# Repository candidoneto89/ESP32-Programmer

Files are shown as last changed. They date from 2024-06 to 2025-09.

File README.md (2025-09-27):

# ESP32-Programmer

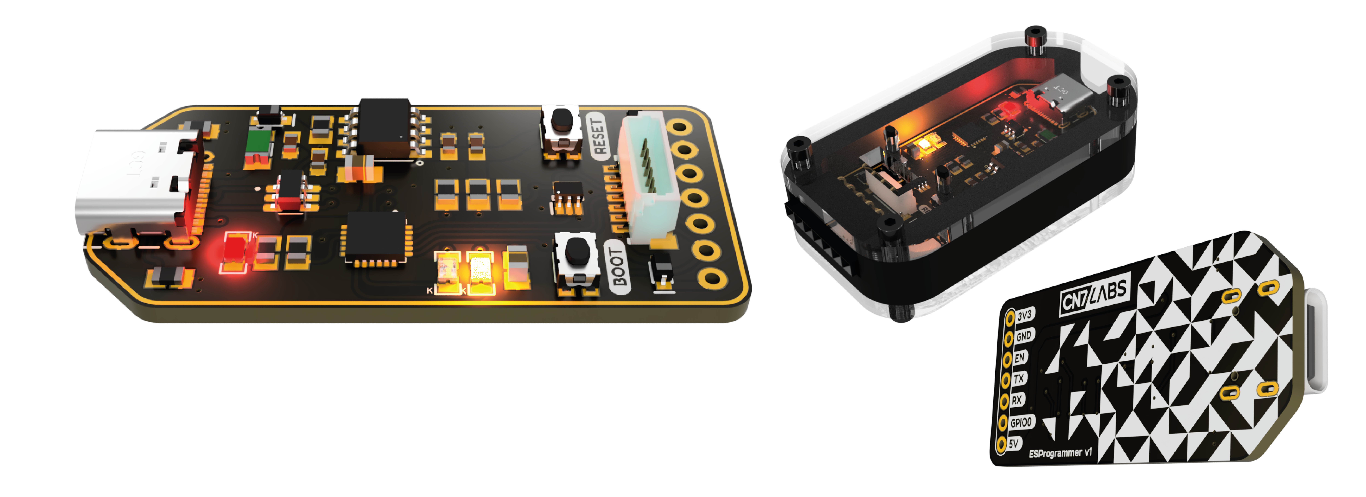
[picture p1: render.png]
ESP32 Programmer


This is a serial bridge for programming custom ESP32 boards, with auto-reset feature, so you shouldn't have to manually push buttons to enter boot mode. The board can also power simple ESP32 boards and has some standard circuit protections. 

**Features:**
- USB-C Connector
- ESD, overcurrent and reverse current protection
- CP2104 enabled USB-to-UART Bridge
- 3.3V ~ 600mA regulator
- Auto-reset circuit
- Boot and Reset buttons.
  
# Building
## PCB BOM

|Parts |Value |Package |Qty|
|---|---|---|---|
|C1, C2, C5 |10uF |0603-CAP |3  |
|C3 |1uF |0603-CAP |1  |
|C4 |10uF |C0805 |1  |
|C6 |1uF |C0805 |1  |
|D1, D2, D3 |BAT60A |SOD-323 |3  |
|F1 |1.5A PTC FUSE |PTC1206 |1  |
|J2 |USB-C-4105_REVA |GCT_USB4105_REVA |1  |
|PWR |RED LED |0805_LED |1  |
|Q1 |UMH3N |SOT65P230X110-6N |1  |
|R3, R4, R10|5.1k |R0805 |3  |
|R5, R8, R9 |10k |R0805 |3  |
|R6 |4.7k |R0805 |1  |
|R7 |100k |R0805 |1  |
|RX |YELLOW LED |0805_LED |1  |
|S1, S2 |KMR621NG SWITCH |KMR621NG_LFS |2  |
|TX |ORANGE LED |0805_LED |1  |
|U1 |CP2104-F03-GM |QFN50P400X400X80-25N|1  |
|U2 |USBLC6-2SC6 |SOT95P280X145-6N |1  |
|U3 |AP2112M-3.3TRG1 |AP2112M-3.3TRG1_DIO |1  |
|X1 |BM07B-SRSS-TBB  |BM07B-SRSS-TB |1  |

## Assembly partlist:

### FDM case:
- 4x M2 3mmx3mm threaded inserts
- 4x M2 5mm Hex Socket Cap Screw (or similar)

### Stacked acrylic case:
- 8x M2 3mmx3mm threaded inserts
- 8x M2 5mm Hex Socket Cap Screw (or similar)

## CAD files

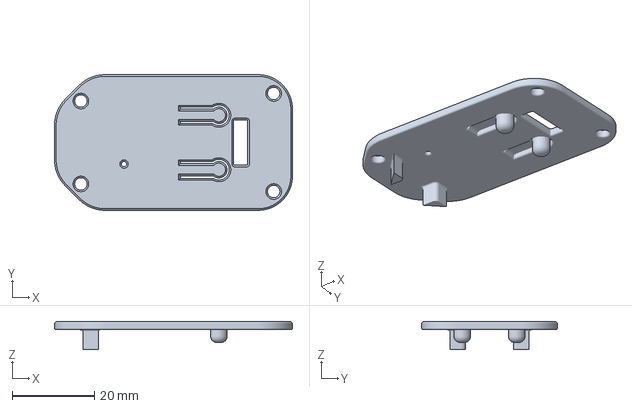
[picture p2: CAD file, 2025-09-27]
Case/fdm-Top.3mf
57.7 x 32.9 x 6.80 mm

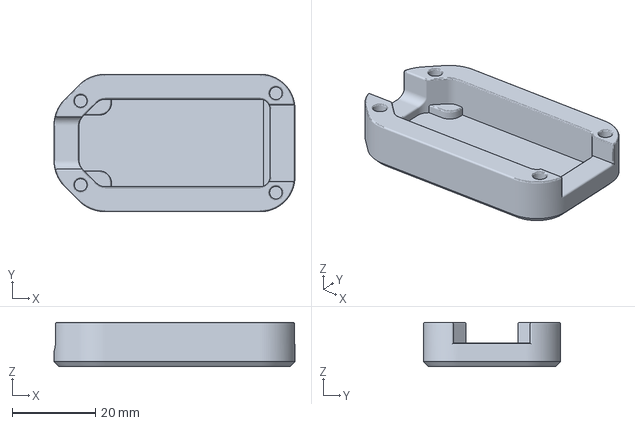
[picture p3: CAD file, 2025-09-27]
Case/fdm-Base.3mf
57.7 x 32.9 x 10.6 mm

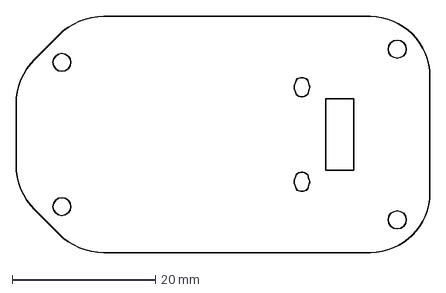
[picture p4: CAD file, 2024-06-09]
Case/topAcrylic.dxf
57.7 x 32.9 mm

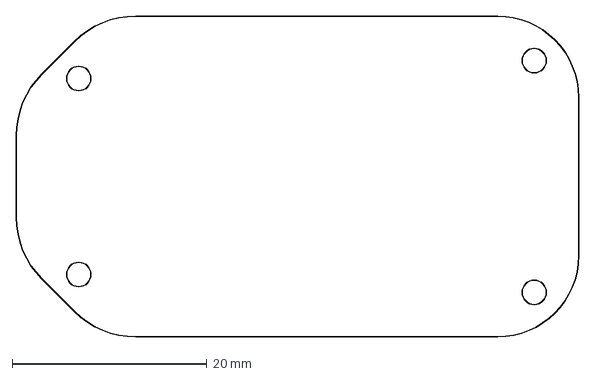
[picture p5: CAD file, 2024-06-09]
Case/bottomAcrylic.dxf
57.7 x 32.9 mm

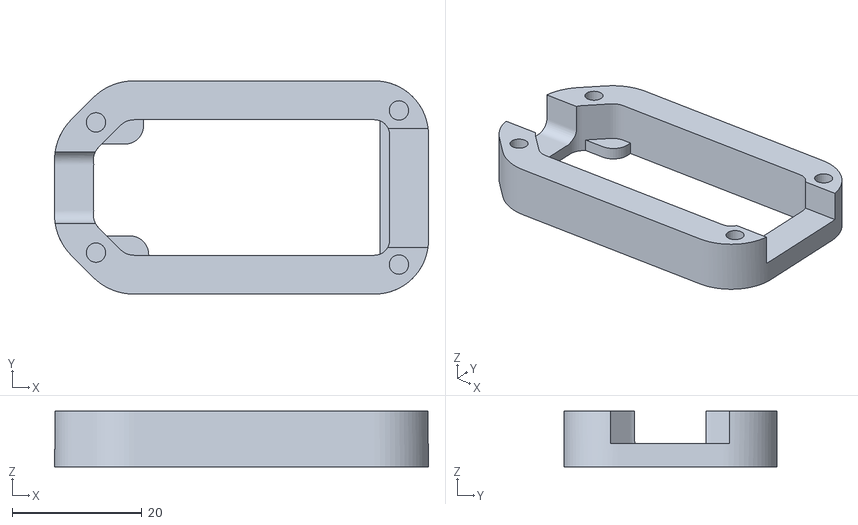
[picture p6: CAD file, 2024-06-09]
Case/Base.stl
57.7 x 32.9 x 8.60

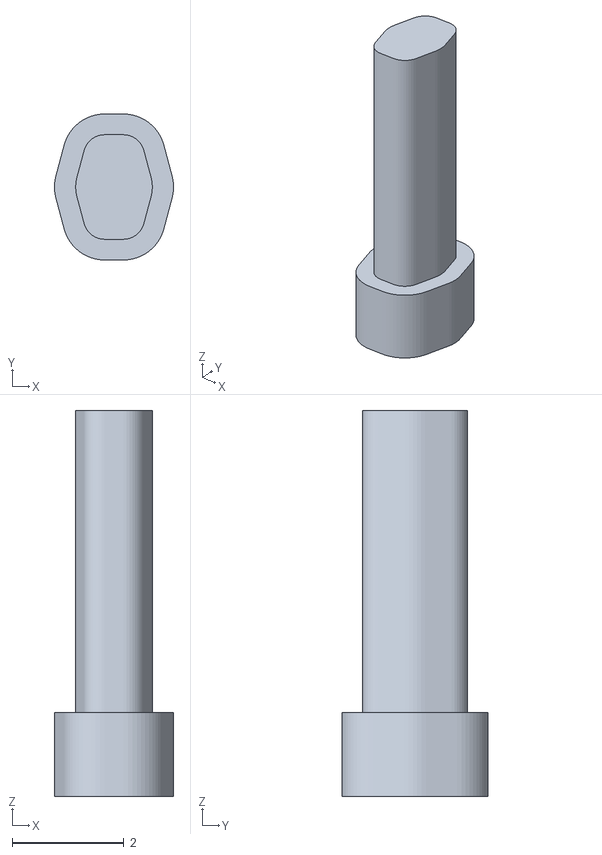
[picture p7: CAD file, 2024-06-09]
Case/Button.stl
2.13 x 2.61 x 6.90

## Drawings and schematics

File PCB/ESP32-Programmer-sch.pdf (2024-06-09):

A

A

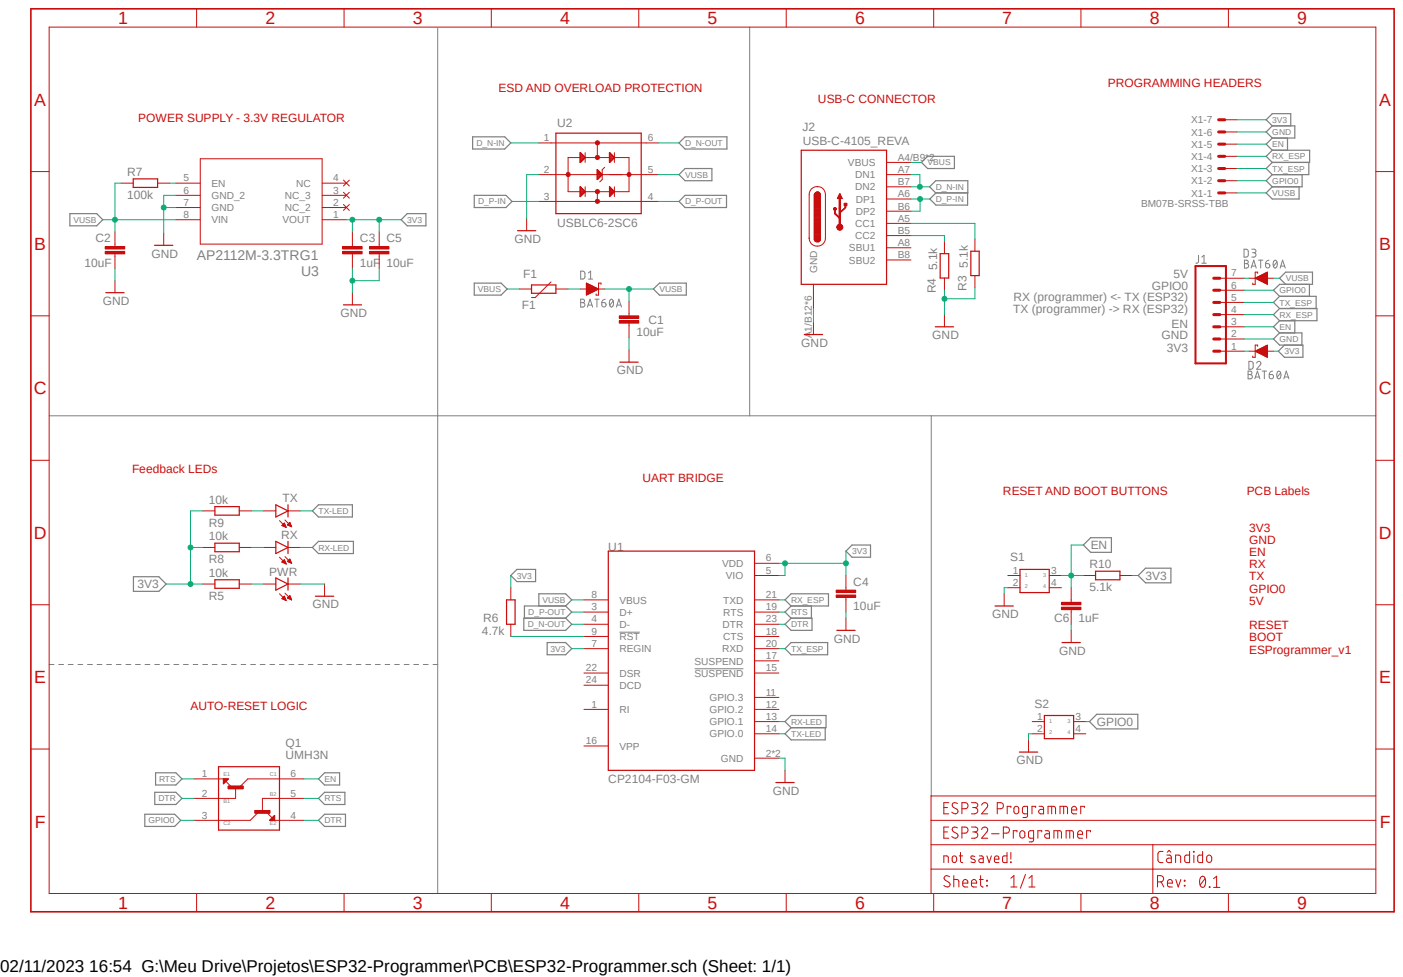
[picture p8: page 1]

POWER SUPPLY - 3.3V REGULATOR | | USB-C CONNECTOR

02/11/2023 16:54 G:\Meu Drive\Projetos\ESP32-Programmer\PCB\ESP32-Programmer.sch (Sheet: 1/1)

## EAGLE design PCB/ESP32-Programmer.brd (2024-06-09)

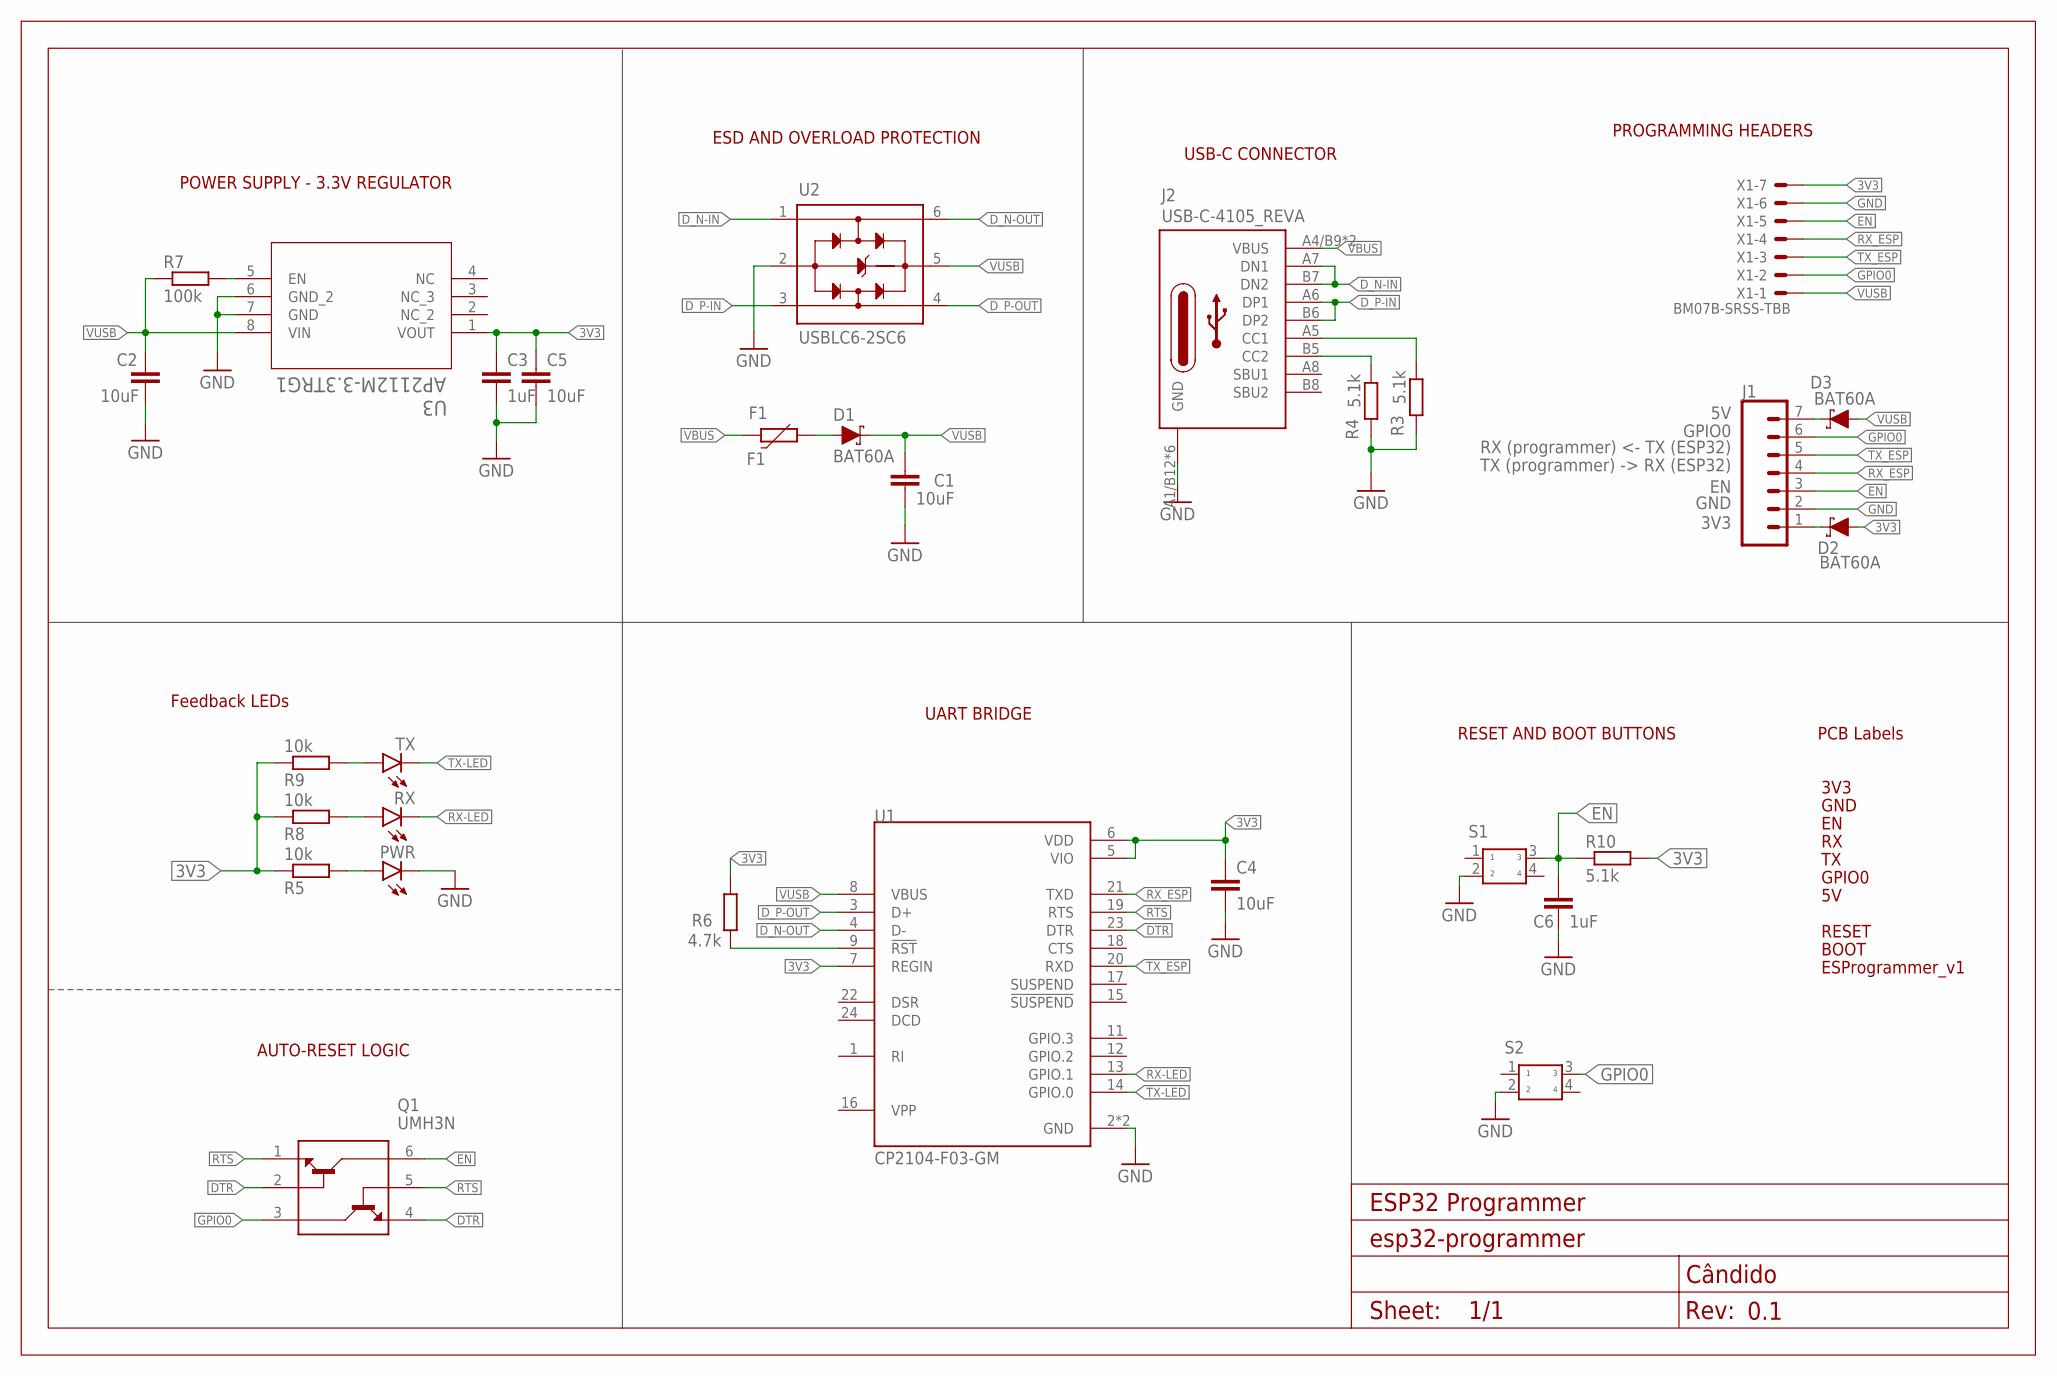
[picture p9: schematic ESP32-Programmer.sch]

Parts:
C1, C2, C5: 10uF; 0603-CAP
C3: 1uF; 0603-CAP
C4: 10uF; C0805
C6: 1uF; C0805
D1, D2, D3: BAT60A; SOD-323
F1: F1; PTC1206
FRAME1: FRAME_A4; FRAME-A4
J1: CONN-07NO_SILK; 1X07_NO_SILK
J2: USB-C-4105_REVA; GCT_USB4105_REVA
PWR: LEDRED-0805; LED_0805_RED
Q1: UMH3N; SOT65P230X110-6N
R3, R4, R10: 5.1k; R0805
R5, R8, R9: 10k; R0805
R6: 4.7k; R0805
R7: 100k; R0805
RX: LEDYELLOW-0805; LED_0805_YELLOW
S1, S2: KMR621NG_LFS
TX: LEDORANGE-0805; LED_0805_ORANGE
U1: CP2104-F03-GM; QFN50P400X400X80-25N
U2: USBLC6-2SC6; SOT95P280X145-6N
U3: AP2112M-3.3TRG1; AP2112M-3.3TRG1_DIO
U$1: BOOT0
U$2: GND0
U$3: 3V30
U$4: 5V0
U$5: EN0
U$6: GPIO00
U$7: RX0
U$8: TX0
U$9: RESET0
U$12: ESPROGRAMMER_V10
X1: BM07B-SRSS-TBB; BM07B-SRSS-TB

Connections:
3V3: C3.1, C4.1, C5.1, D2.A, R5.1, R6.2, R8.1, R9.1, R10.2, U1.5 (VIO), U1.6 (VDD), U1.7 (REGIN), U3.1 (VOUT), X1.7
CC1: J2.A5 (CC1), R3.1
CC2: J2.B5 (CC2), R4.1
DTR: Q1.2 (B1), Q1.4 (E2), U1.23 (DTR)
D_N-IN: J2.A7 (DN1), J2.B7 (DN2), U2.1 (I/O1_IN)
D_N-OUT: U1.4 (D-), U2.6 (I/O1_OUT)
D_P-IN: J2.A6 (DP1), J2.B6 (DP2), U2.3 (I/O2_IN)
D_P-OUT: U1.3 (D+), U2.4 (I/O2_OUT)
EN: C6.1, J1.3, Q1.6 (C1), R10.1, S1.3, X1.5
GND: C1.2, C2.2, C3.2, C4.2, C5.2, C6.2, J1.2, J2.A1/B12 (GND), J2.B1/A12 (GND), J2.G1 (GND), J2.G2 (GND), J2.G3 (GND), J2.G4 (GND), PWR.C, R3.2, R4.2, S1.2, S2.2, U1.2 (GND), U1.25 (GND), U2.2 (GND), U3.6 (GND_2), U3.7 (GND), X1.6
GPIO0: J1.6, Q1.3 (C2), S2.3, X1.2
unnamed: R6.1, U1.9 (!RST)
unnamed: D2.C, J1.1
unnamed: D3.C, J1.7
unnamed: PWR.A, R5.2
unnamed: R7.2, U3.5 (EN)
unnamed: R8.2, RX.A
unnamed: R9.2, TX.A
unnamed: D1.A, F1.2
RTS: Q1.1 (E1), Q1.5 (B2), U1.19 (RTS)
RX-LED: RX.C, U1.13 (GPIO.1)
RX_ESP: J1.4, U1.21 (TXD), X1.4
TX-LED: TX.C, U1.14 (GPIO.0)
TX_ESP: J1.5, U1.20 (RXD), X1.3
VBUS: F1.1, J2.A4/B9 (VBUS), J2.B4/A9 (VBUS)
VUSB: C1.1, C2.1, D1.C, D3.A, R7.1, U1.8 (VBUS), U2.5 (VBUS), U3.8 (VIN), X1.1

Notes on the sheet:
POWER SUPPLY - 3.3V REGULATOR
USB-C CONNECTOR
UART BRIDGE
AUTO-RESET LOGIC
RX (programmer) <- TX (ESP32)
TX (programmer) -> RX (ESP32)
3V3
GPIO0
GND
Feedback LEDs
ESD AND OVERLOAD PROTECTION
PROGRAMMING HEADERS
RESET AND BOOT BUTTONS
PCB Labels

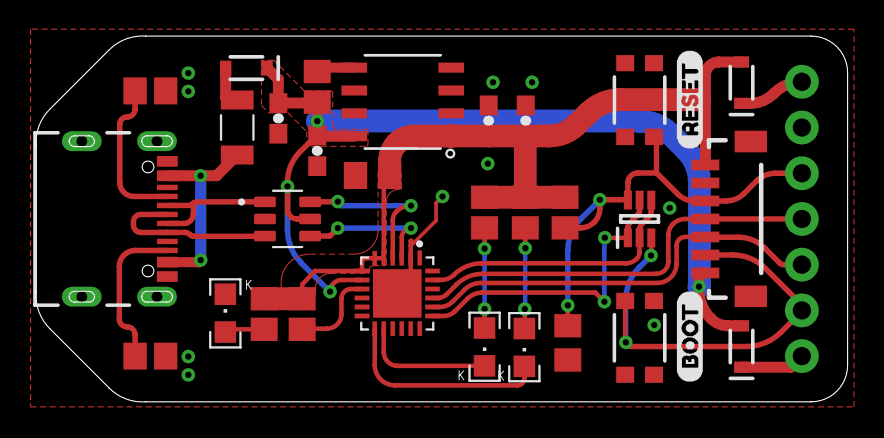
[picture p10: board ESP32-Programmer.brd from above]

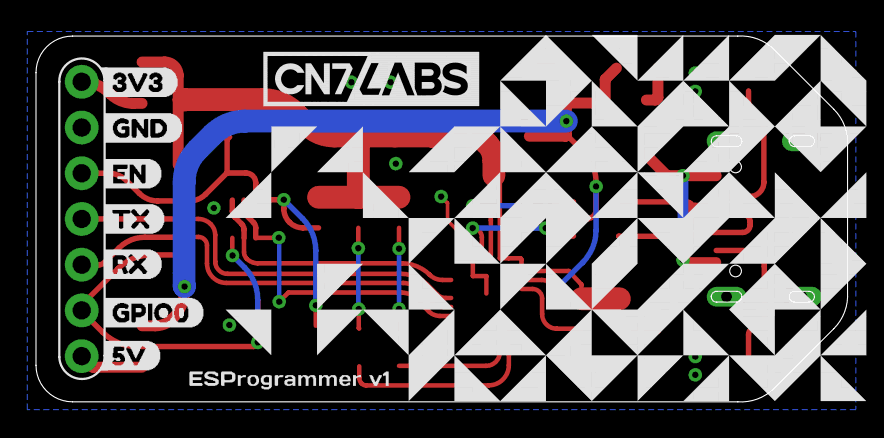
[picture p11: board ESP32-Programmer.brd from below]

Board: 2 copper layers, 45.1 x 20.3 mm, 43 parts (10 on the bottom side), 26 nets.

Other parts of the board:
U$10: CN7LABS-1
U$11: TRUCHET-TILE-1

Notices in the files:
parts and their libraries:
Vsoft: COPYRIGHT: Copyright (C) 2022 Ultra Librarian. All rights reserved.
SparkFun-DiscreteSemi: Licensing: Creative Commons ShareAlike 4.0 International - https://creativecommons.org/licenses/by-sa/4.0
